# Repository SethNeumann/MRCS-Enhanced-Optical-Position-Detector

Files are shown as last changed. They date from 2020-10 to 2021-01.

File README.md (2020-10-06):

# REPO NAME: MRCS-Enhanced-Optical-Position-Detector
## License: Creative Commons Attribution-NonCommercial-ShareAlike

Optical Position Detectors are useful when precise position detection is required (clearing a staging throat, for example), 
when the area to be detected is small (an "OS" section in a CTC system) or where resistance wheel sets cannot be applied 
and current detection can't be used.  The Enhanced Optical Position Detector is based on Geoff Bunza's DAPD and provides a 
fixed turn-on and turn-off delay and high power output stage similar to Bruce Chubb's DCC-OD (so if you need an optical 
detector that's electrically compatible with a cpOD or DCC-OD, EOPD is for you!).

The EOPD uses Geoff's self-calibrating detection circuit, so you don't need to adjust for ambient light level.  Note the 
circuit won't work in the dark unless you substitute infrared Photo transistors and provide an infrared illumination source.  
The supply voltage range is 5-15 volts and the output is a negative-true open collector which will sink up to 600 mA at up 
to 40VDC.  Size is 1.15" x 1.75 x 0.5" high"

Either 2 PT-19 photo transistors or “Da Fingah” are provided. a reference and another to be placed between the rails. You may
solder the reference onto the board if the board will be mounted where is has the same illumination as the track or both may be mounted remotely.

The EOPD is a compatible Modular Signaling System (MSS) Optical Detector

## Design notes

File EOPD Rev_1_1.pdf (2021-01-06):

Page 1 | www.modelrailroadcontrolsystems.com | January 6, 2021

# Enhanced Optical Position Detector

Revision 1.1 January 6, 2021

Seth Neumann, seth@modelrailroadcontrolsystems.com

Introduction
This document describes the Enhance Optical Position Detector and how to assemble and install it.

Revision History
v0.1 | 12/19/17 SCN
v0.2 | 1/6/17 SCN – show Rev 2 board
v0.3 | 1/22/18 SCN – identify emitter, collector on Phototransistor, Rev0.3
v0.3 | 4/2/18 SCN – connections for “Da Fingah”
V.5 | 10/5/20 SCN – clean up, correct error on detector 1 and 2 functions
V.7 | Updated Schematic and table to show typical test voltages SCN
V 1.0 | This is the “Production” document SCN
V 1.1 | Added notes for “no delay” SCN

Page 2 | www.modelrailroadcontrolsystems.com | January 6, 2021

## Table of Contents

1 INTRODUCTION | 3 2 IDENTIFICATION AND INFORMATION | 4 2.1. BOARD IDENTIFICATION | 4 3 THEORY OF OPERATION (MOSTLY FROM GEOFF’S SMA-23) | 7 4 OPTIONS | 8 3.1. TIMING VALUE R4 | 8 3.2. PHOTO TRANSISTOR | 8 3.3. OUTPUT TRANSISTOR | 8 3.4. CONNECTORS | 8 3.5. SENSORS | 9 3.6. DETAILED ASSEMBLY | 10 5 TESTING | 11 6 INSTALLATION AND CONNECTIONS | 12

## Table of Figures

FIGURE 1 - REV 1.0 BOARD WITH NO CONNECTOR AND NO ON-BOARD REFERENCE DETECTOR | 4
FIGURE 2 - REV 2.0 BOARD WITH SCREW TERMINALS AND NO ON-BOARD REFERENCE DETECTOR (NOTE REV 3 IS IDENTICAL EXCEPT THEY ARE WHITE AND LABELS HAVE BEEN MOVED FOR BETTER READABILITY WITH SCREW CONNECTORS). ... 4
FIGURE 3 - REV 3.0.4 EOPD BOARD - | 5
FIGURE 4 - REV 2, 3 SCHEMATIC | 6
FIGURE 6 - PT19 SENSORS – NOTE THE “FLAG” SIDE, SHORT LEAD IS THE COLLECTOR | 9
FIGURE 7 - "DA FINGAH" WITH 0.100 HEADER | 9
FIGURE 8 - EOPD REV 3, 4 PARTS LAYOUT | 10

## Table of Tables

TABLE 1- BILL OF MATERIALS REV 2.0/3.0 | 5
TABLE 2 - VOLTAGES UNCOVERED (ILLUMINATED)/COVERED | 6

Page 3 | www.modelrailroadcontrolsystems.com | January 6, 2021

### 1 INTRODUCTION

This board is a variation on Geoff Bunza’s Differential Absolute Position Detector, described in his MRH blog post SMA-23. http://model-railroad-hobbyist.com/node/26133

- The EOPD operates on 4-15 volts and draws about 3 mA,
- any type of photo transistor can be used as a sensor, just be sure both the reference and track sensor are of the same type
- uses standard semiconductors available from Jameco and similar suppliers
- includes a fixed delay of about 1.5 seconds avoid false detection and drop out
- Open collector active low output sinks up to 600mA at 40V (be sure to provide snubber diodes on inductive loads)
- Optionally uses “Da Fingah” a single piece detector with surface mounted detectors that slides under the rail between two ties and has an on-board reference detector.

All components are through-hole technology for ease of assembly and repair.

All connection pads are standardized on .100” centers. This provides a wide range of interconnect options and components. Connection schemes include screw terminal blocks, header pin connectors (male and female), soldered right angle headers, and direct soldered wires.

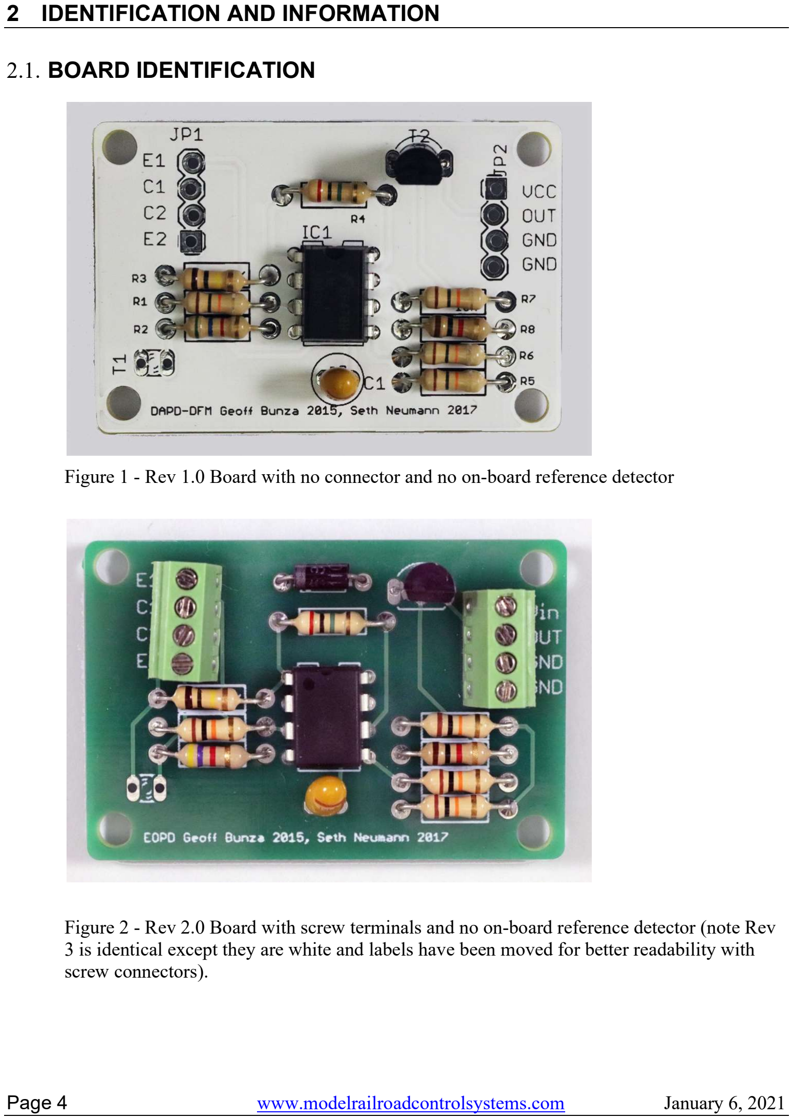
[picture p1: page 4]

Page 4 | www.modelrailroadcontrolsystems.com | January 6, 2021

### 2 IDENTIFICATION AND INFORMATION

### 2.1. BOARD IDENTIFICATION

Figure 1 - Rev 1.0 Board with no connector and no on-board reference detector

Figure 2 - Rev 2.0 Board with screw terminals and no on-board reference detector (note Rev 3 is identical except they are white and labels have been moved for better readability with screw connectors).

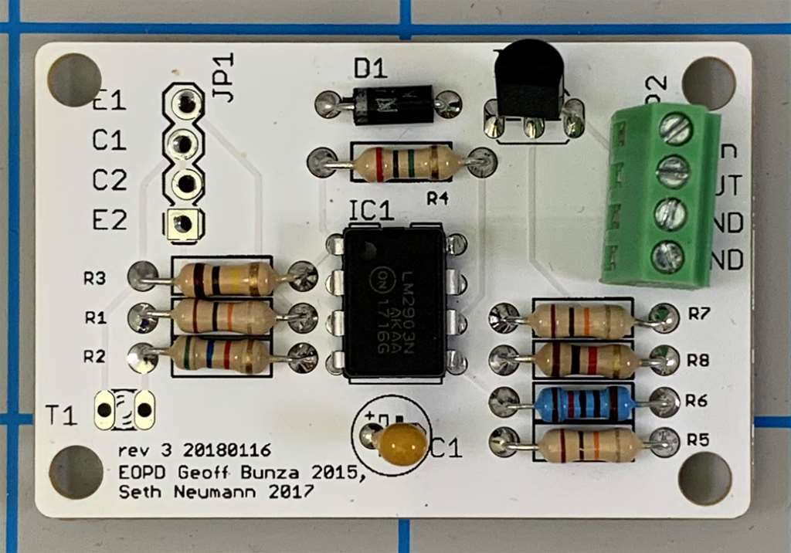
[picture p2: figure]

Page 5 | www.modelrailroadcontrolsystems.com | January 6, 2021

Figure 3 - Rev 3.0.4 EOPD board -
Cosmetic changes for better legibility. Rev 4 is the same but panelized, 6 up.
Qty | Value | Device | Package | Parts | Description
1 1 uF Tant | | CPOL-USE2.5-5 | E2,5-5 | C1 | POLARIZED CAPACITOR, Tant
1 1N5819 | | Schottky diode, 1A 40V | DO41 | D1 | Schottky diode, 1A 40V
4 10K | | RESISTORPTH-1/4W | AXIAL-0.4 | R1, R5, R6, R7 | Resistor
1 100K | | RESISTORPTH-1/4W | AXIAL-0.4 | R3 | Resistor
1 1K | | RESISTORPTH-1/4W | AXIAL-0.4 | R8 | Resistor
1 2M | | RESISTORPTH-1/4W | AXIAL-0.4 | R4 | Resistor
1 5.6K | | RESISTORPTH-1/4W | AXIAL-0.4 | R2 | Resistor
1 1N5819 | | Diode Shottky 1N5819 | AXIAL-0.3 | D1 | Diode Shottky 1N5819
1 2N4401 | | 2N4401 | TO92-EBC | T2 | NPN Transistor
1 LM2903N | | LM2903N | DIL08 | IC1 | COMPARATOR
1 PCB | | EOPD | PCB | PCB | EOPD

Table 1- Bill of Materials Rev 2.0/3.0

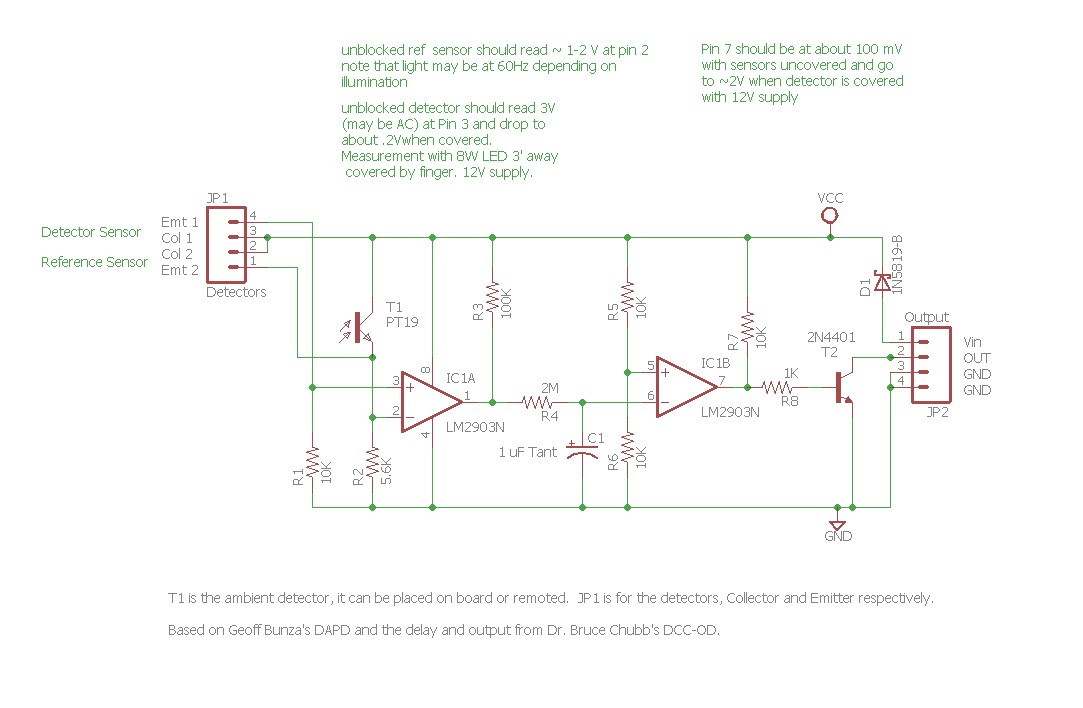
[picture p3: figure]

Page 6 | www.modelrailroadcontrolsystems.com | January 6, 2021

Figure 4 - Rev 2, 3 Schematic

(Rev 1 is the same except for the blocking diode D1, which protects against reversing power to the circuit)

Table of typical Occupancy Sensor uncovered /sensor covered voltages at pin 2,3 and 5,6 based on supply voltages of 5, and 12V. Test conditions are 8W LED bulb 3’ above work bench, covering and uncovering the sensor on “Da Fingah.” Ranges refer to the 1VAC signal because the illumination is AC. This may vary depending on your set-up so these are starting values only.

Description | U1 Pin | 5V | 12V
Reference sensor | 2 | 2V sine Wave with bottom at 2v | 1-2V sine wave over 1V/1
Occupancy sensor | 3 | 1V sine Wave with bottom at 1/0.3V | 3/.2
Timer reference | 5 | 2.5/2.5 | 6/6
Timer output | 7 | .1V/1.2V | .1/2

Table 2 - Voltages Uncovered (illuminated)/Covered

Page 7 | www.modelrailroadcontrolsystems.com | January 6, 2021

### 3 THEORY OF OPERATION (MOSTLY FROM GEOFF’S SMA-23)

The detector uses two small ambient light sensors based on a photo-transistor (a PT204 or BPX81 through-hole part). The ambient light hitting each sensor is compared. When the light level of the sensor between the rails falls below the light level of the nearby sensor, the output of the first Op Amp (LM2903) goes low (to ground).

Note well that the emitter resistors are different, to force the sensor “off” under clear ambient conditions. The light sensitivity of this detector is mostly in the same range visible to the human eye. This means the light in your layout room that the modeler sees is what is relevant. Geoff reports that he can lower the light level to be darker than what I would consider to be a “normal” comfort level for operation, and still have the detector working. Likewise, very bright light internal lighting works well too. However, absolutely no light does mean no detection. If you want to place the detector in a lightless tunnel or building, simply add a lighted LED or incandescent lamp nearby and you should enable correct operation. Remember both sensors need to see about the same unobstructed “ambient” light levels. If the sensor not between the rails sees a much lower light level, the sensor may never turn on. If the sensor not between the rails sees a much higher light level, the sensor may always be on.

The second segment of the Op Amp uses the delay circuit from Dr Chubb’s DCC-OD and is set by C1 and R4 to about 1.5 seconds. See “Options” if you prefer a different delay value. The output of the second segment (pin 7) is inverting and R7 (10K pull up) and base current limiting resistor R8 (1K) turn T2 on when the output is high.

Many first time DIYers are perplexed or even disturbed by the concept of active low open collectors. The idea that a low signal is “TRUE” is fundamentally upsetting to some people. However, this arrangement provides greater current drive at lower cost as well offering the possibility of tying multiple outputs together in a “WIRE-OR” configuration. A good example is if you are using optical detectors for a short track section you may still want to use two close together to avoid the possibility of a train stopping with a gap between cars over the sensor. Just use two detectors and wire them both to your logic input (with a suitable pull up, say 4.7K). Either of the sensors showing occupied (the “OR”) will now give you a correct occupancy input.

Note I have freely taken from Geoff and Bruce’s work but they’re both in the public domain. Any errors or circuit problems that have crept in are solely my responsibility.

Page 8 | www.modelrailroadcontrolsystems.com | January 6, 2021

### 4 OPTIONS

3.1.TIMING VALUE R4

The default value of 2M ohms yields a turn on and off delay of about 1.5 seconds. This is a compromise value that prevents most false activations and dropouts. You can substitute resistors between 1M and 3M to get delays from about 0.75 to 3 seconds. If you need a value beyond .75 – 3 try using a different value for C1.
If you want no delay (e.g. direction stick relay input, indicator of gap between cars for remote uncoupling) delete C1 and use 100K for R4.

3.2.PHOTO TRANSISTOR

Geoff picked the BPX81/ PT204 because it is relatively inexpensive and easily available, but he states that almost any photo transistor will work, which has been our experience. Feel free to substitute if your favorite parts house doesn’t stock one of these and you want to minimize order minimums and shipping.

Pads are provided to mount the reference detector on board as T1. You can also connect the sensor externally on pins E2 and C2. “Da Fingah” also connects to the detector pads using a 4 conductor 0.100 cable. Check orientation for correct operation (momentarily connecting Da Fingah upside down won’t hurt it).

3.3.OUTPUT TRANSISTOR

I copied the output stage of Dr Bruce Chubb’s DCC-OD as that is a widely used current occupancy detector and most do-it-yourself model railroaders have some around. Bruce uses the 2N4401 (40V @ 600mA collector current) for an open collector output but any similar switching transistor will do. If you have 2N3904 or 2N2222(A) in your parts bin, they’ll work fine. Check specs if you need to drive a load at the margin and be sure to put snubber diodes across inductive loads!

3.4.CONNECTORS

- The input (sensor) connectors are on 0.100 centers (staggered slightly to hold the connectors in place during assembly). While our standard connector is the 0.100 screw terminal, you may substitute any other 0.100 connector you prefer. If you are ordering an assembled and tested unit from MRCS and you would prefer a different connector, please contact us at sales@modelrailroadcontrolsystems.com and indicate your preference and we’ll provide a quotation.
- Power and output are on the right-hand connector.

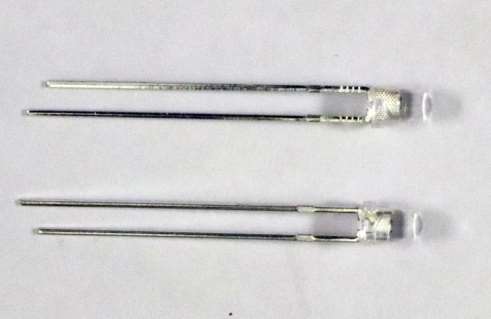
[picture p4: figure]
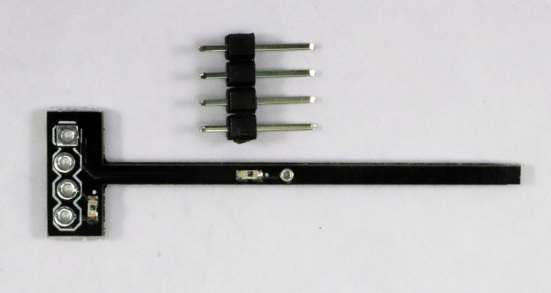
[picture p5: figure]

Page 9 | www.modelrailroadcontrolsystems.com | January 6, 2021

3.5.SENSORS

- The EOPD is available with no sensors (provide your own), a pair of PT19s (package is like a 3mm LED) or with “Da Fingah” which has 2 surface mount sensors and slides between HO (and some
N) scale ties.

Figure 5 - PT19 Sensors – note the “Flag” side, short lead is the collector.

Figure 6 - "Da Fingah" with 0.100 header

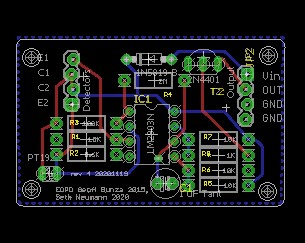
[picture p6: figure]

Page 10 | www.modelrailroadcontrolsystems.com | January 6, 2021

3.6.DETAILED ASSEMBLY

Figure 7 - EOPD Rev 3, 4 Parts Layout
All of the components are through-hole technology with wire leads. A lead bender is a useful tool is for forming the leads at 90 degrees for easy insertion into the pad holes. The general rule is install the lowest components first, working towards components that are higher off the board . Start by inserting the lower height components (resistors and diode). This enables you to support the low components as you solder them. Refer to the options you want and note which components will be used.

[ ] Resistors, Diodes
[ ] Install Resistors R1 through R8 and diode D1. Try to keep the gold tolerance band on the right side for easier reading of values.
[ ] Install diode D1, observe polarity.

[ ] IC LM2903
[ ] install U1, notch pointing up

[ ] Tantalum Capacitor

[ ] Install C1, observe polarity

[ ] Onboard reference T1, if used

[ ] Output Transistor T2

[ ] Connectors JP1, JP2
[ ] Install JP1, JP2 using desired connector

Page 11 | www.modelrailroadcontrolsystems.com | January 6, 2021

### 5 TESTING

Testing your Enhanced Optical Position Detector is quick and simple:

### 1. Mount the board securely on standoffs

2. Apply positive voltage (5-15 VDC) between Vin (+) and one of the GND terminals on the right side of the board.
3. Connect an LED (observe polarity) in series with a suitable limiting resistor (RED Led, 330 Ohms at 5 Volts, 1,000 ohms at 12V, 1,200 ohms at 15V) between the Vin terminal and the out terminal
4. Connect photo transistors (either install T1 on the board as reference or connect T1 across the E2/C2 connections) and the sense photo transistor across E1/C1 on the left side of the board. The Cs are the collectors (short lead, flag side in the clear part) and the emitters, Es are the long leads.
5. Momentarily cover the sense proto transistor while leaving the reference photo transistor illuminated. After about 2 seconds the LED on the output will come on. Remove the obstruction and the output should turn off after another 1.5 seconds.

Page 12 | www.modelrailroadcontrolsystems.com | January 6, 2021

### 6 INSTALLATION AND CONNECTIONS

Looking at the right-hand connector there are terminals (or header pins depending on how the EOPD was assembled) for Power (0-18V), an open collector, negative true (that it is, it goes to ground when it’s detecting) output and 2 ground terminals, one for the power supply and another to connect to a common ground for the load.

The left-hand connector is for the remote sensors. If you’ve equipped your EOPD and Fingah with 0.100 headers an 0.100 4 conductor cable can make the connection. Try to keep the sensors within about 2 meters (6.5’) of the EOPD as the input is high impedance and may pick up noise from DCC or lighting circuits. The output is low impedance and can run anywhere in the layout room on 24-gauge wire, be sure the EOPD and any layout control nodes are referenced to the same ground.

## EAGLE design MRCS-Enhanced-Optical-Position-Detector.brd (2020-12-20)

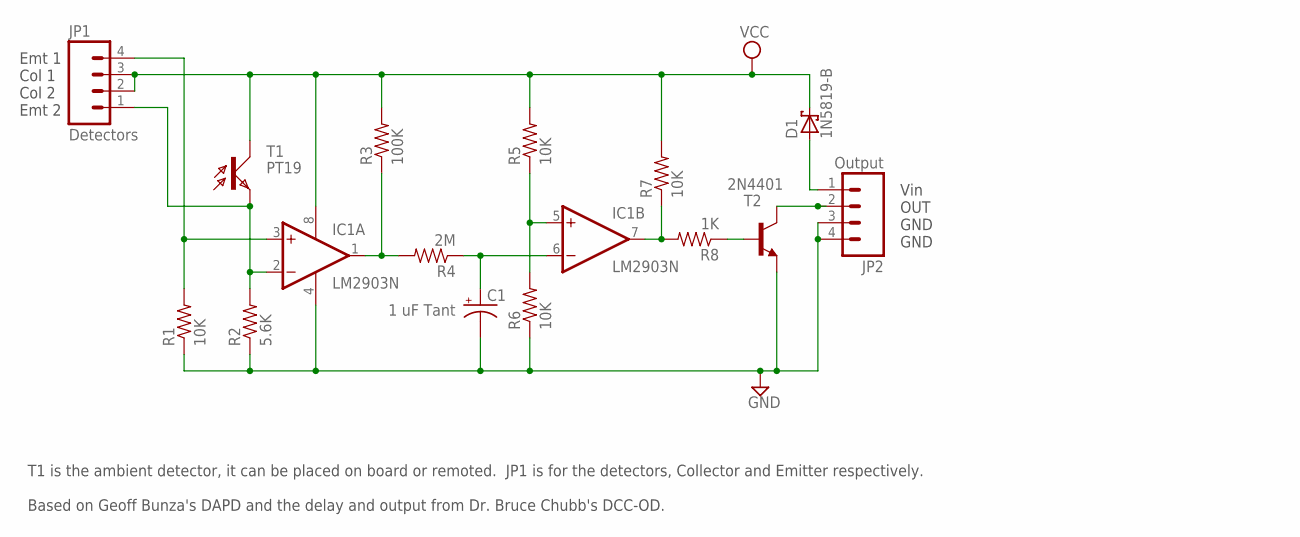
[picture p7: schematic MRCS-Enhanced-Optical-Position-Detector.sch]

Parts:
C1: 1 uF Tant; E2,5-5
D1: 1N5819-B; DO41-7.6
IC1: LM2903N; DIL08
JP1: Detectors; 1X04_LOCK
JP2: Output; 1X04_LOCK
R1, R5, R6, R7: 10K; AXIAL-0.4
R2: 5.6K; AXIAL-0.4
R3: 100K; AXIAL-0.4
R4: 2M; AXIAL-0.4
R8: 1K; AXIAL-0.4
T1: PT19; BPX81
T2: 2N4401; TO92-EBC

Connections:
GND: C1.-, IC1.4 (V-), JP2.3, JP2.4, R1.P$1 (1), R2.P$1 (1), R6.P$1 (1), T2.E
unnamed: IC1.2 (-IN), JP1.1, R2.P$2 (2), T1.E
unnamed: C1.+, IC1.6 (-IN), R4.P$1 (1)
unnamed: IC1.3 (+IN), JP1.4, R1.P$2 (2)
unnamed: IC1.1 (OUT), R3.P$1 (1), R4.P$2 (2)
unnamed: IC1.7 (OUT), R7.P$1 (1), R8.P$2 (2)
unnamed: IC1.5 (+IN), R5.P$1 (1), R6.P$2 (2)
unnamed: R8.P$1 (1), T2.B
unnamed: JP2.2, T2.C
VCC: D1.C, IC1.8 (V+), JP1.2, JP1.3, R3.P$2 (2), R5.P$2 (2), R7.P$2 (2), T1.C
VIN: D1.A, JP2.1

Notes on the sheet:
Vin OUT GND GND
Emt 1 Col 1 Col 2 Emt 2
T1 is the ambient detector, it can be placed on board or remoted. JP1 is for the detectors, Collector and Emitter respectively. Based on Geoff Bunza's DAPD and the delay and output from Dr. Bruce Chubb's DCC-OD.

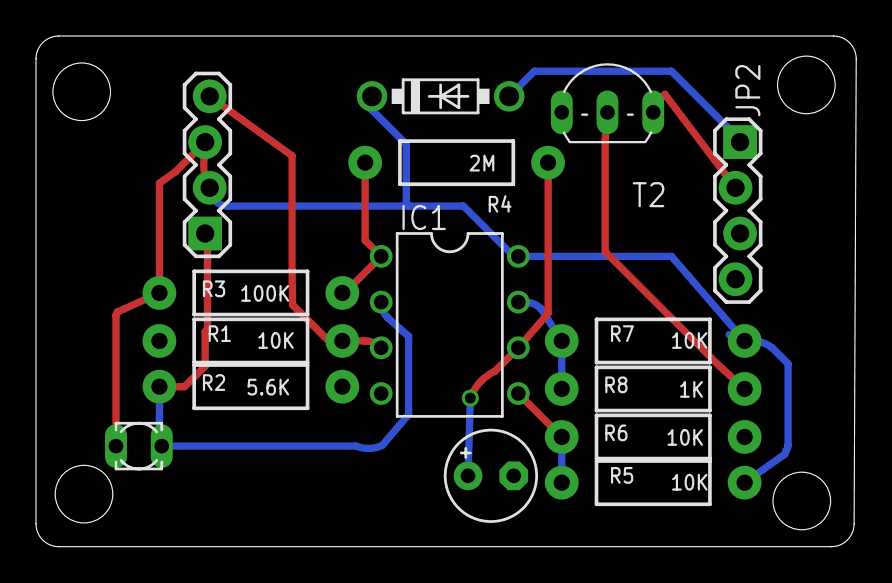
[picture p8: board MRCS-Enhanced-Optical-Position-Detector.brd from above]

Board: 2 copper layers, 45.6 x 28.4 mm, 17 parts (0 on the bottom side), 11 nets.

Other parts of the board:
U$1: MRCSLOGOBTM
U$3: CA-PROP65WARNING

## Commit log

2020-10-06 initial commit
    imported from old Eagle project directory
    [MRCS-Enhanced-Optical-Position-Detector.brd, MRCS-Enhanced-Optical-Position-Detector.sch]
2020-11-21 clean up before panelizing
    miscellaneous clean up of the file preperatory to panelizing
    [EOPD BOM 20201005.xlsx, MRCS-Enhanced-Optical-Position-Detector.brd, MRCS-Enhanced-Optical-Position-Detector.sch]
2020-12-20 changes for legibility and work file cleanup
    cleaned out work and derivative files
    [MRCS-Enhanced-Optical-Position-Detector.brd]
2020-12-29 Final documentation of EOPD
    added tables of test voltages, clean up, rebuilt TOC and tables of figures, tables
2020-12-29 Update EOPD Rev_1.pdf
    printed the whole doc, not just 1st page
2021-01-06 Added values for no-delay
    Values for no-delay version
    [MRCS-Enhanced-Optical-Position-Detector.sch]

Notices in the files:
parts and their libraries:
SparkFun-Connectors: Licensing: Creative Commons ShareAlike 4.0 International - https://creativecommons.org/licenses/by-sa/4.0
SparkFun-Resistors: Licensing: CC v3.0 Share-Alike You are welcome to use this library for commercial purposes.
